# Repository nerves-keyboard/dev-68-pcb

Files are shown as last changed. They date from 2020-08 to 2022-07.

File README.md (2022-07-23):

# Dev-68

A 68-key development keyboard designed for working on the [Xebow](https://github.com/ElixirSeattle/xebow) firmware.

- [Bill of materials](https://docs.google.com/spreadsheets/d/1IPxDRe5p0AkolHPQgk4m-Z4O2ABlp4nutEiS4CgZYm4/edit?usp=sharing)

- [Layout](http://www.keyboard-layout-editor.com/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'&_w:2.25%3B&=Enter%3B&@_w:2.25%3B&=Shift&=Z&=X&=C&=V&=B&=N&=M&=%3C%0A,&=%3E%0A.&=%3F%0A%2F%2F&_w:2.75%3B&=Shift&_x:0.25%3B&=%E2%86%91%3B&@_w:1.25%3B&=Ctrl&_w:1.25%3B&=Super&_w:1.25%3B&=Alt&_w:6.25%3B&=&_w:1.25%3B&=Fn&_w:1.25%3B&=Alt&_w:1.25%3B&=Ctrl&_x:0.5%3B&=%E2%86%90&=%E2%86%93&=%E2%86%92)

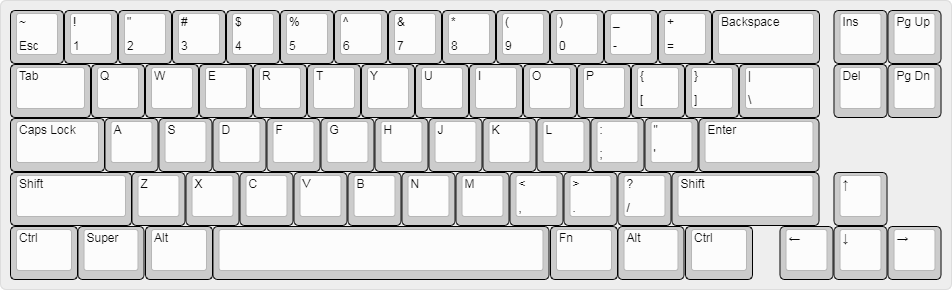
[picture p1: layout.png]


- PCB

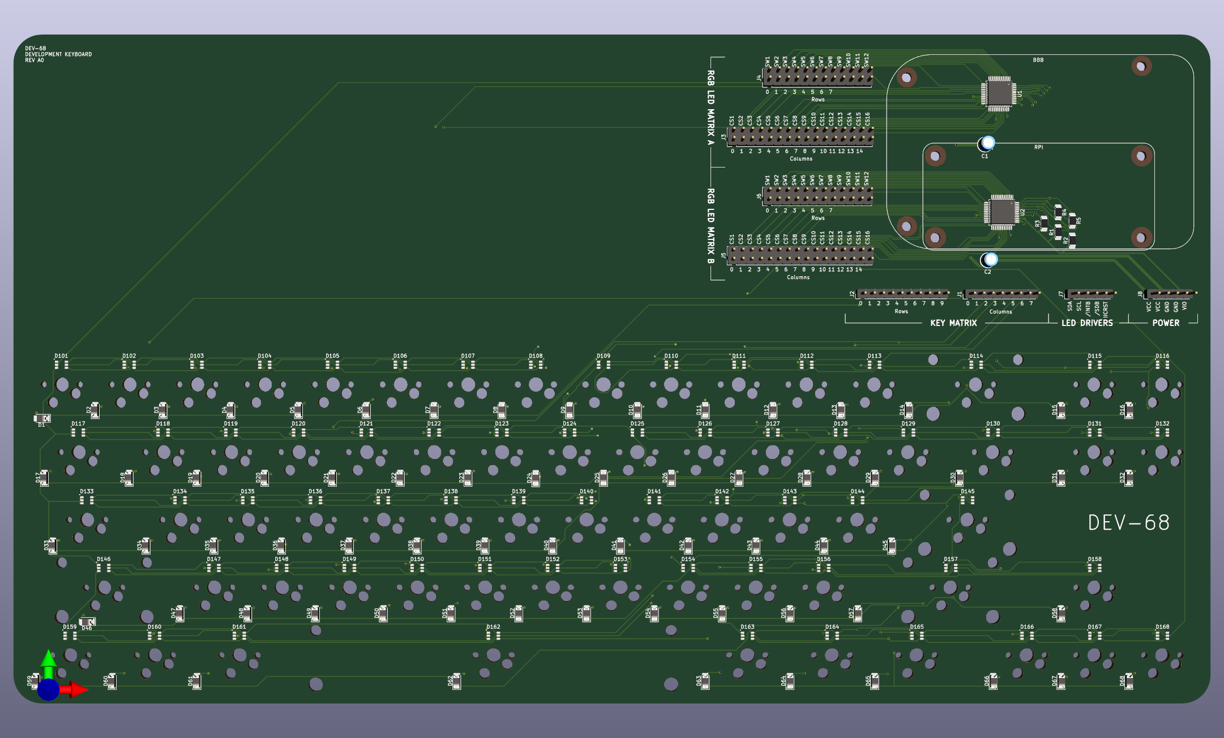
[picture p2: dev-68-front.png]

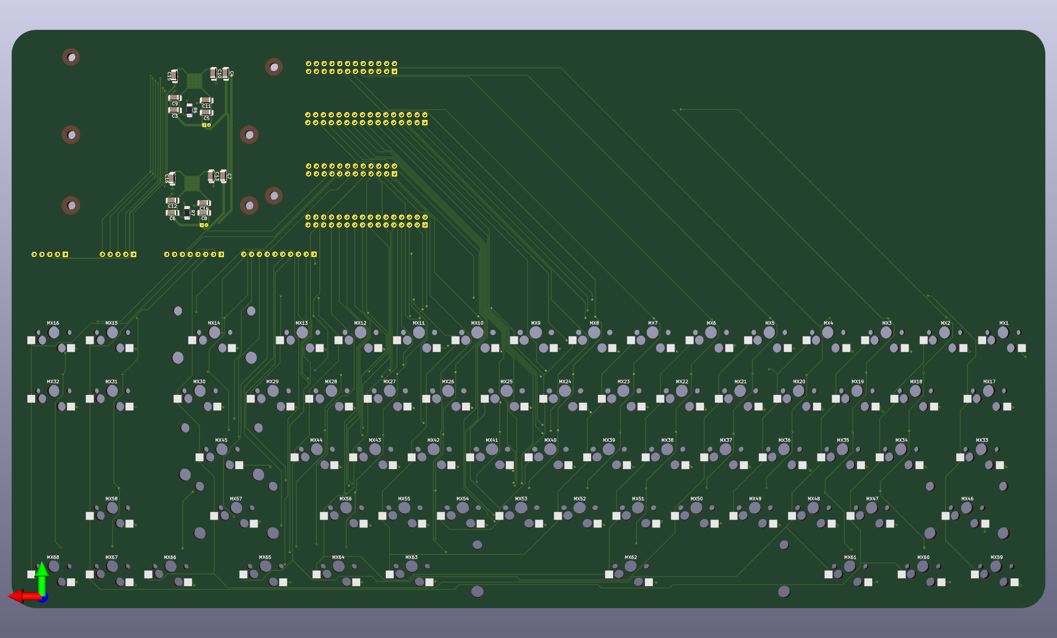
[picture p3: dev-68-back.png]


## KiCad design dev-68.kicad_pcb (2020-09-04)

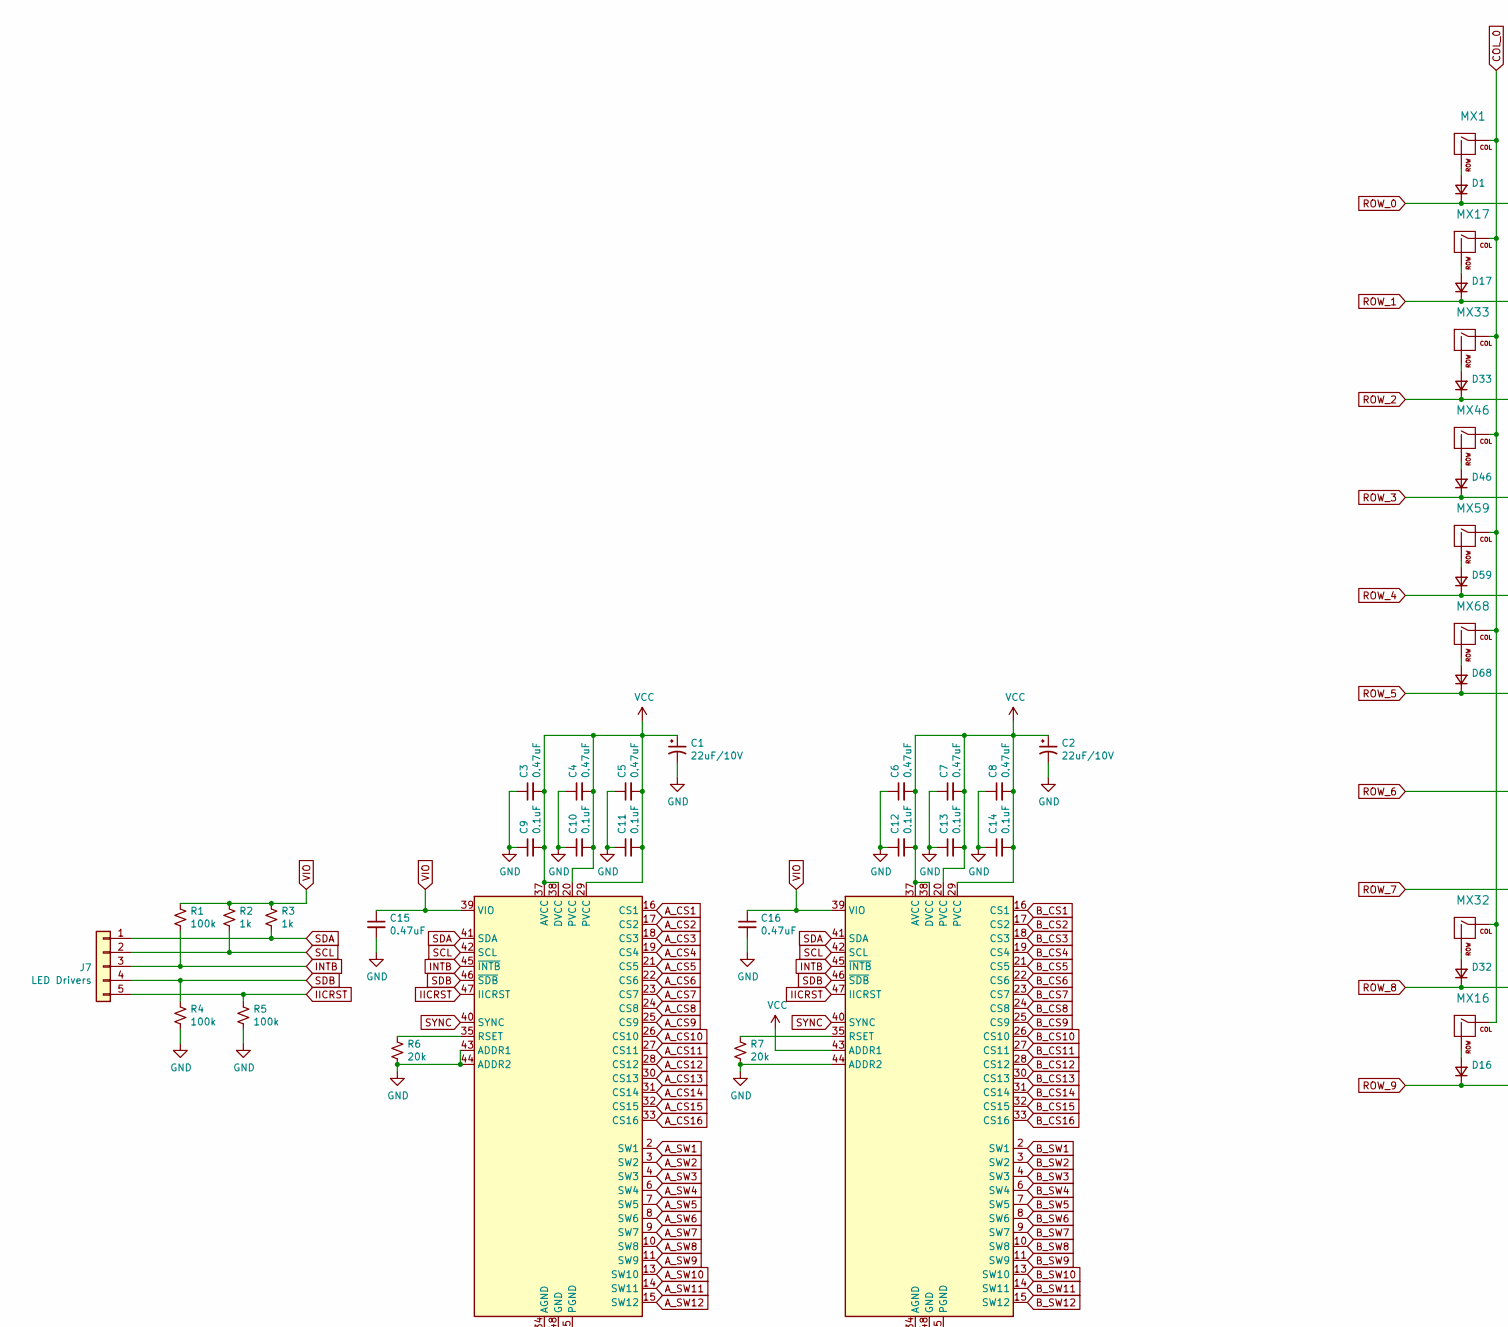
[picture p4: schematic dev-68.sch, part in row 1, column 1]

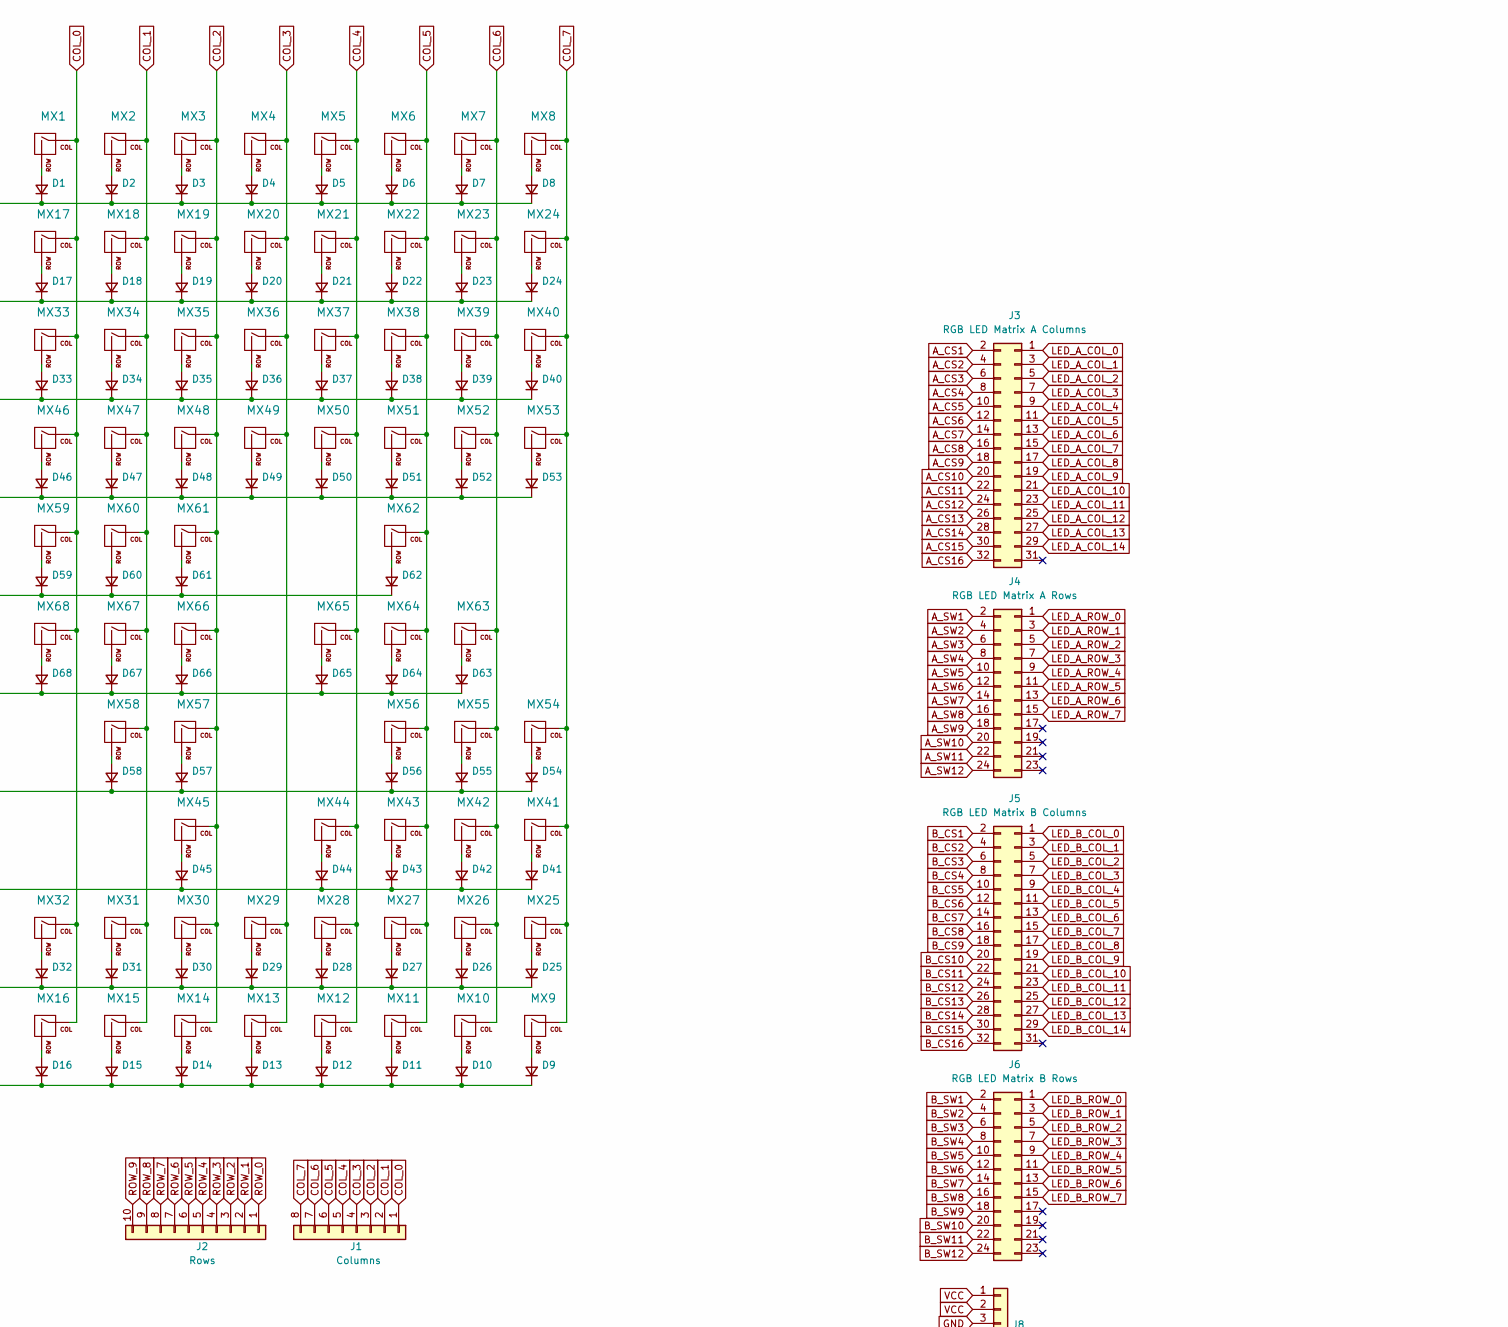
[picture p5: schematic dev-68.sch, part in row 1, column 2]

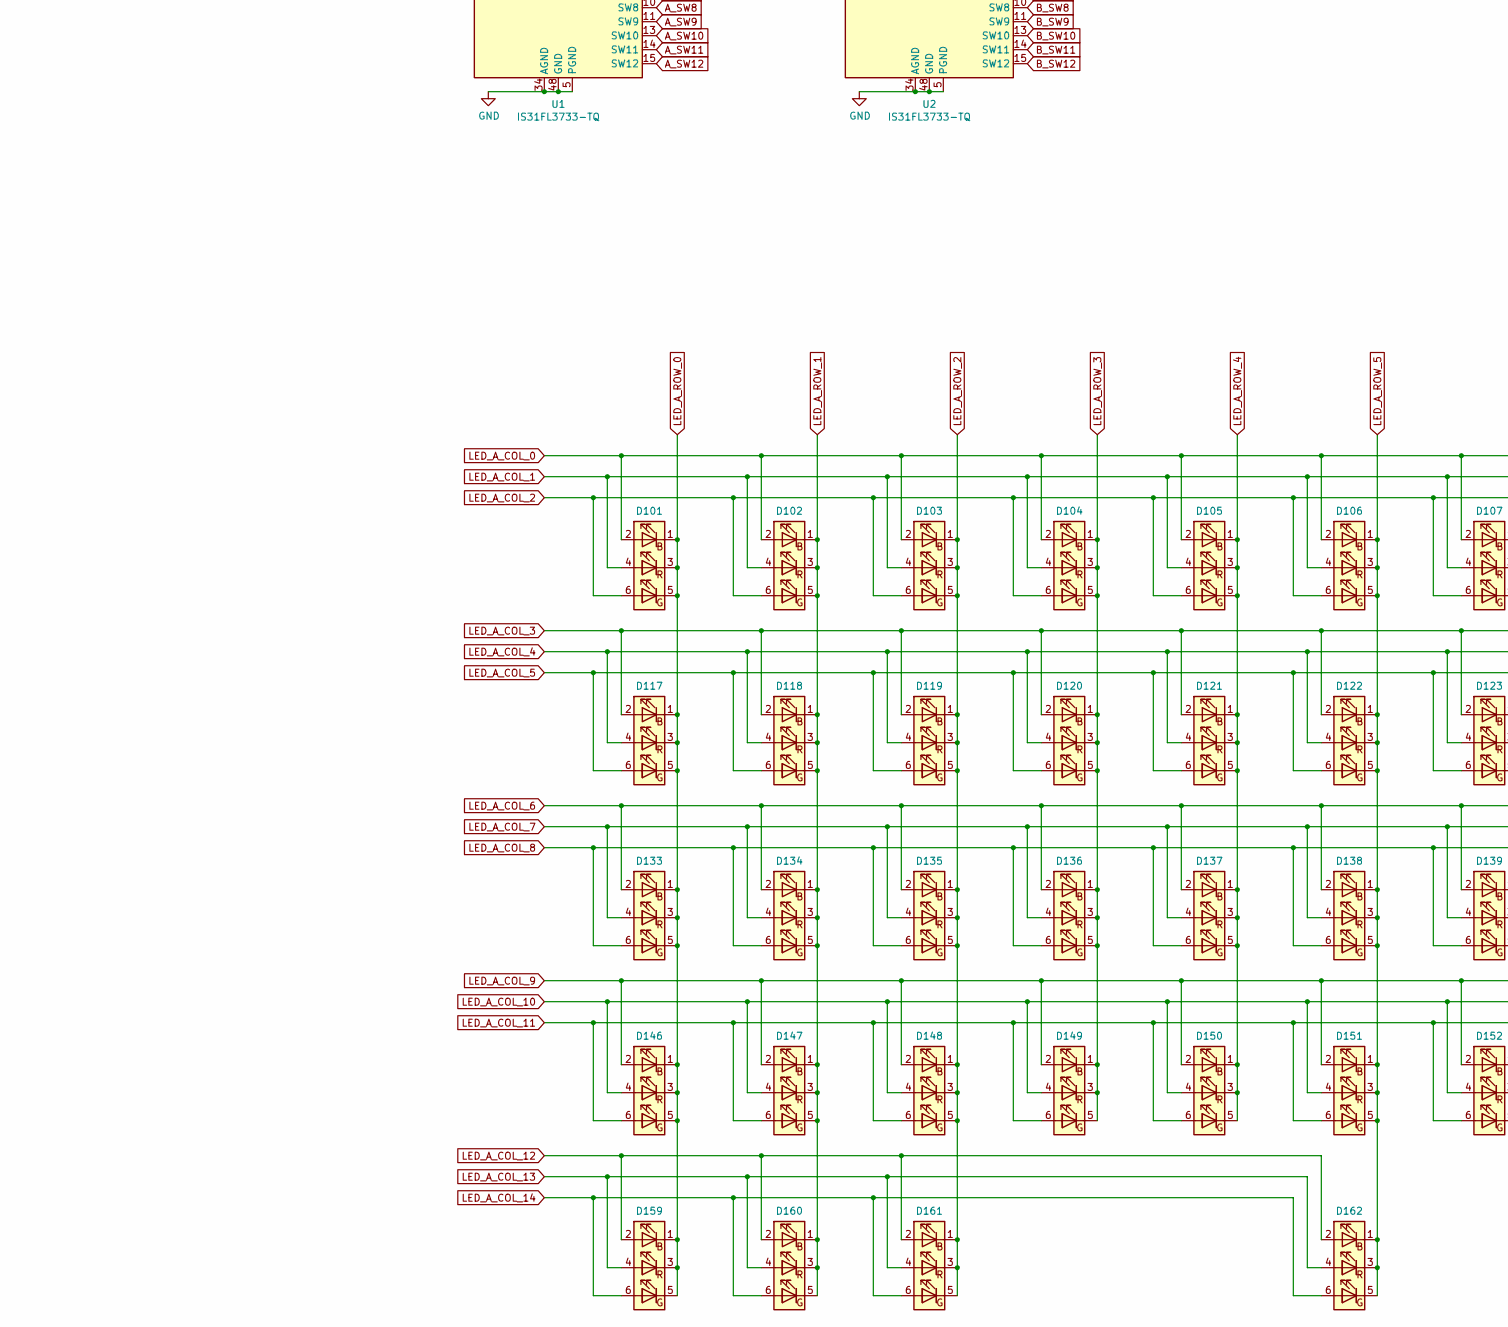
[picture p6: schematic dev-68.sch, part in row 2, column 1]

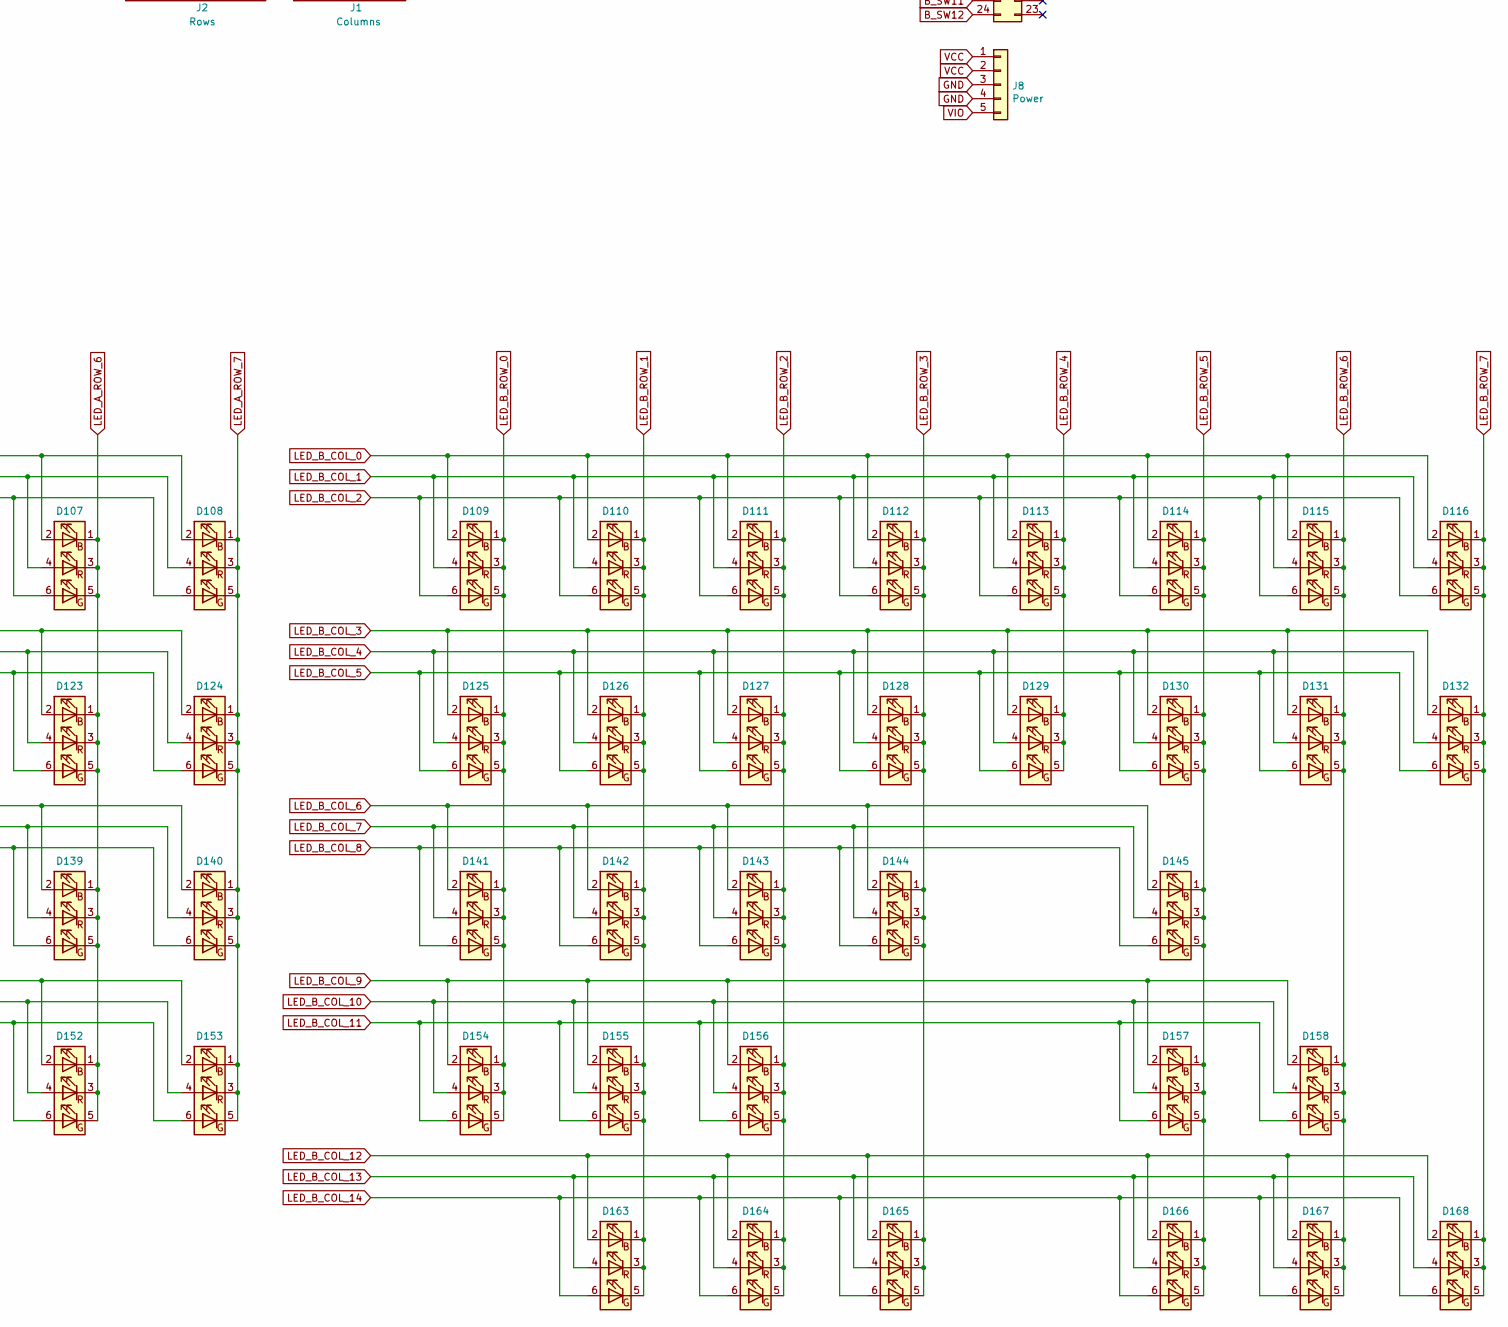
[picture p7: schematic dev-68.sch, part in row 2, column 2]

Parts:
C1, C2: 22uF/10V; CP_Radial_D4.0mm_P1.50mm
C3, C4, C5, C6, C7, C8, C15, C16: 0.47uF; C_1206_3216Metric_Pad1.42x1.75mm_HandSolder
C9, C10, C11, C12, C13, C14: 0.1uF; C_1206_3216Metric_Pad1.42x1.75mm_HandSolder
D1, D2, D3, D4, D5, D6, D7, D8, D9, D10, D11, D12, D13, D14, D15, D16, D17, D18, D19, D20, D21, D22, D23, D24, D25, D26, D27, D28, D29, D30, D31, D32, D33, D34, D35, D36, D37, D38, D39, D40, D41, D42, D43, D44, D45, D46, D47, D48, D49, D50, D51, D52, D53, D54, D55, D56, D57, D58, D59, D60, D61, D62, D63, D64, D65, D66, D67, D68: D_small; D_1206_3216Metric_Pad1.42x1.75mm_HandSolder
D101, D102, D103, D104, D105, D106, D107, D108, D109, D110, D111, D112, D113, D114, D115, D116, D117, D118, D119, D120, D121, D122, D123, D124, D125, D126, D127, D128, D129, D130, D131, D132, D133, D134, D135, D136, D137, D138, D139, D140, D141, D142, D143, D144, D145, D146, D147, D148, D149, D150, D151, D152, D153, D154, D155, D156, D157, D158, D159, D160, D161, D162, D163, D164, D165, D166, D167, D168: LED_RGB; Wurth_PLCC6
J1: Columns; PinHeader_1x08_P2.54mm_Vertical
J2: Rows; PinHeader_1x10_P2.54mm_Vertical
J3: RGB LED Matrix A Columns; PinHeader_2x16_P2.54mm_Vertical
J4: RGB LED Matrix A Rows; PinHeader_2x12_P2.54mm_Vertical
J5: RGB LED Matrix B Columns; PinHeader_2x16_P2.54mm_Vertical
J6: RGB LED Matrix B Rows; PinHeader_2x12_P2.54mm_Vertical
J7: LED Drivers; PinHeader_1x05_P2.54mm_Vertical
J8: Power; PinHeader_1x05_P2.54mm_Vertical
MX1, MX2, MX3, MX4, MX5, MX6, MX7, MX8, MX9, MX10, MX11, MX12, MX13, MX15, MX16, MX18, MX19, MX20, MX21, MX22, MX23, MX24, MX25, MX26, MX27, MX28, MX29, MX31, MX32, MX34, MX35, MX36, MX37, MX38, MX39, MX40, MX41, MX42, MX43, MX44, MX47, MX48, MX49, MX50, MX51, MX52, MX53, MX54, MX55, MX56, MX58, MX66, MX67, MX68: MX-NoLED; MXOnly-1U-Hotswap
MX14: MX-NoLED; MXOnly-2U-Hotswap-ReversedStabilizers
MX17, MX30: MX-NoLED; MXOnly-1.5U-Hotswap
MX33: MX-NoLED; MXOnly-1.75U-Hotswap
MX45, MX46: MX-NoLED; MXOnly-2.25U-Hotswap-ReversedStabilizers
MX57: MX-NoLED; MXOnly-2.75U-Hotswap-ReversedStabilizers
MX59, MX60, MX61, MX63, MX64, MX65: MX-NoLED; MXOnly-1.25U-Hotswap
MX62: MX-NoLED; MXOnly-6.25U-Hotswap-ReversedStabilizers
R1, R4, R5: 100k; R_1206_3216Metric_Pad1.42x1.75mm_HandSolder
R2, R3: 1k; R_1206_3216Metric_Pad1.42x1.75mm_HandSolder
R6, R7: 20k; R_1206_3216Metric_Pad1.42x1.75mm_HandSolder
U1, U2: IS31FL3733-TQ; TQFP-48-1EP_7x7mm_P0.5mm_EP5x5mm

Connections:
A_CS1: J3.2, U1.16 (CS1)
A_CS2: J3.4, U1.17 (CS2)
A_CS3: J3.6, U1.18 (CS3)
A_CS4: J3.8, U1.19 (CS4)
A_CS5: J3.10, U1.21 (CS5)
A_CS6: J3.12, U1.22 (CS6)
A_CS7: J3.14, U1.23 (CS7)
A_CS8: J3.16, U1.24 (CS8)
A_CS9: J3.18, U1.25 (CS9)
A_CS10: J3.20, U1.26 (CS10)
A_CS11: J3.22, U1.27 (CS11)
A_CS12: J3.24, U1.28 (CS12)
A_CS13: J3.26, U1.30 (CS13)
A_CS14: J3.28, U1.31 (CS14)
A_CS15: J3.30, U1.32 (CS15)
A_CS16: J3.32, U1.33 (CS16)
A_SW1: J4.2, U1.2 (SW1)
A_SW2: J4.4, U1.3 (SW2)
A_SW3: J4.6, U1.4 (SW3)
A_SW4: J4.8, U1.6 (SW4)
A_SW5: J4.10, U1.7 (SW5)
A_SW6: J4.12, U1.8 (SW6)
A_SW7: J4.14, U1.9 (SW7)
A_SW8: J4.16, U1.10 (SW8)
A_SW9: J4.18, U1.11 (SW9)
A_SW10: J4.20, U1.13 (SW10)
A_SW11: J4.22, U1.14 (SW11)
A_SW12: J4.24, U1.15 (SW12)
B_CS1: J5.2, U2.16 (CS1)
B_CS2: J5.4, U2.17 (CS2)
B_CS3: J5.6, U2.18 (CS3)
B_CS4: J5.8, U2.19 (CS4)
B_CS5: J5.10, U2.21 (CS5)
B_CS6: J5.12, U2.22 (CS6)
B_CS7: J5.14, U2.23 (CS7)
B_CS8: J5.16, U2.24 (CS8)
B_CS9: J5.18, U2.25 (CS9)
B_CS10: J5.20, U2.26 (CS10)
B_CS11: J5.22, U2.27 (CS11)
B_CS12: J5.24, U2.28 (CS12)
B_CS13: J5.26, U2.30 (CS13)
B_CS14: J5.28, U2.31 (CS14)
B_CS15: J5.30, U2.32 (CS15)
B_CS16: J5.32, U2.33 (CS16)
B_SW1: J6.2, U2.2 (SW1)
B_SW2: J6.4, U2.3 (SW2)
B_SW3: J6.6, U2.4 (SW3)
B_SW4: J6.8, U2.6 (SW4)
B_SW5: J6.10, U2.7 (SW5)
B_SW6: J6.12, U2.8 (SW6)
B_SW7: J6.14, U2.9 (SW7)
B_SW8: J6.16, U2.10 (SW8)
B_SW9: J6.18, U2.11 (SW9)
B_SW10: J6.20, U2.13 (SW10)
B_SW11: J6.22, U2.14 (SW11)
B_SW12: J6.24, U2.15 (SW12)
COL_0: J1.1, MX1.1 (COL), MX16.1 (COL), MX17.1 (COL), MX32.1 (COL), MX33.1 (COL), MX46.1 (COL), MX59.1 (COL), MX68.1 (COL)
COL_1: J1.2, MX2.1 (COL), MX15.1 (COL), MX18.1 (COL), MX31.1 (COL), MX34.1 (COL), MX47.1 (COL), MX58.1 (COL), MX60.1 (COL), MX67.1 (COL)
COL_2: J1.3, MX3.1 (COL), MX14.1 (COL), MX19.1 (COL), MX30.1 (COL), MX35.1 (COL), MX45.1 (COL), MX48.1 (COL), MX57.1 (COL), MX61.1 (COL), MX66.1 (COL)
COL_3: J1.4, MX4.1 (COL), MX13.1 (COL), MX20.1 (COL), MX29.1 (COL), MX36.1 (COL), MX49.1 (COL)
COL_4: J1.5, MX5.1 (COL), MX12.1 (COL), MX21.1 (COL), MX28.1 (COL), MX37.1 (COL), MX44.1 (COL), MX50.1 (COL), MX65.1 (COL)
COL_5: J1.6, MX6.1 (COL), MX11.1 (COL), MX22.1 (COL), MX27.1 (COL), MX38.1 (COL), MX43.1 (COL), MX51.1 (COL), MX56.1 (COL), MX62.1 (COL), MX64.1 (COL)
COL_6: J1.7, MX7.1 (COL), MX10.1 (COL), MX23.1 (COL), MX26.1 (COL), MX39.1 (COL), MX42.1 (COL), MX52.1 (COL), MX55.1 (COL), MX63.1 (COL)
COL_7: J1.8, MX8.1 (COL), MX9.1 (COL), MX24.1 (COL), MX25.1 (COL), MX40.1 (COL), MX41.1 (COL), MX53.1 (COL), MX54.1 (COL)
GND: C1.2, C2.2, C3.1, C4.1, C5.1, C6.1, C7.1, C8.1, C9.1, C10.1, C11.1, C12.1, C13.1, C14.1, C15.2, C16.2, J8.3, J8.4, R4.2, R5.2, R6.2, R7.2, U1.5 (PGND), U1.12 (PGND), U1.34 (AGND), U1.43 (ADDR1), U1.44 (ADDR2), U1.48 (GND), U1.49 (GND), U2.5 (PGND), U2.12 (PGND), U2.34 (AGND), U2.44 (ADDR2), U2.48 (GND), U2.49 (GND)
IICRST: J7.5, R5.1, U1.47 (IICRST), U2.47 (IICRST)
INTB: J7.3, R1.2, U1.45 (~INTB), U2.45 (~INTB)
LED_A_COL_0: D101.2 (BA), D102.2 (BA), D103.2 (BA), D104.2 (BA), D105.2 (BA), D106.2 (BA), D107.2 (BA), D108.2 (BA), J3.1
LED_A_COL_1: D101.4 (RA), D102.4 (RA), D103.4 (RA), D104.4 (RA), D105.4 (RA), D106.4 (RA), D107.4 (RA), D108.4 (RA), J3.3
LED_A_COL_2: D101.6 (GA), D102.6 (GA), D103.6 (GA), D104.6 (GA), D105.6 (GA), D106.6 (GA), D107.6 (GA), D108.6 (GA), J3.5
LED_A_COL_3: D117.2 (BA), D118.2 (BA), D119.2 (BA), D120.2 (BA), D121.2 (BA), D122.2 (BA), D123.2 (BA), D124.2 (BA), J3.7
LED_A_COL_4: D117.4 (RA), D118.4 (RA), D119.4 (RA), D120.4 (RA), D121.4 (RA), D122.4 (RA), D123.4 (RA), D124.4 (RA), J3.9
LED_A_COL_5: D117.6 (GA), D118.6 (GA), D119.6 (GA), D120.6 (GA), D121.6 (GA), D122.6 (GA), D123.6 (GA), D124.6 (GA), J3.11
LED_A_COL_6: D133.2 (BA), D134.2 (BA), D135.2 (BA), D136.2 (BA), D137.2 (BA), D138.2 (BA), D139.2 (BA), D140.2 (BA), J3.13
LED_A_COL_7: D133.4 (RA), D134.4 (RA), D135.4 (RA), D136.4 (RA), D137.4 (RA), D138.4 (RA), D139.4 (RA), D140.4 (RA), J3.15
LED_A_COL_8: D133.6 (GA), D134.6 (GA), D135.6 (GA), D136.6 (GA), D137.6 (GA), D138.6 (GA), D139.6 (GA), D140.6 (GA), J3.17
LED_A_COL_9: D146.2 (BA), D147.2 (BA), D148.2 (BA), D149.2 (BA), D150.2 (BA), D151.2 (BA), D152.2 (BA), D153.2 (BA), J3.19
LED_A_COL_10: D146.4 (RA), D147.4 (RA), D148.4 (RA), D149.4 (RA), D150.4 (RA), D151.4 (RA), D152.4 (RA), D153.4 (RA), J3.21
LED_A_COL_11: D146.6 (GA), D147.6 (GA), D148.6 (GA), D149.6 (GA), D150.6 (GA), D151.6 (GA), D152.6 (GA), D153.6 (GA), J3.23
LED_A_COL_12: D159.2 (BA), D160.2 (BA), D161.2 (BA), D162.2 (BA), J3.25
LED_A_COL_13: D159.4 (RA), D160.4 (RA), D161.4 (RA), D162.4 (RA), J3.27
LED_A_COL_14: D159.6 (GA), D160.6 (GA), D161.6 (GA), D162.6 (GA), J3.29
LED_A_ROW_0: D101.1 (BK), D101.3 (RK), D101.5 (GK), D117.1 (BK), D117.3 (RK), D117.5 (GK), D133.1 (BK), D133.3 (RK), D133.5 (GK), D146.1 (BK), D146.3 (RK), D146.5 (GK), D159.1 (BK), D159.3 (RK), D159.5 (GK), J4.1
LED_A_ROW_1: D102.1 (BK), D102.3 (RK), D102.5 (GK), D118.1 (BK), D118.3 (RK), D118.5 (GK), D134.1 (BK), D134.3 (RK), D134.5 (GK), D147.1 (BK), D147.3 (RK), D147.5 (GK), D160.1 (BK), D160.3 (RK), D160.5 (GK), J4.3
LED_A_ROW_2: D103.1 (BK), D103.3 (RK), D103.5 (GK), D119.1 (BK), D119.3 (RK), D119.5 (GK), D135.1 (BK), D135.3 (RK), D135.5 (GK), D148.1 (BK), D148.3 (RK), D148.5 (GK), D161.1 (BK), D161.3 (RK), D161.5 (GK), J4.5
LED_A_ROW_3: D104.1 (BK), D104.3 (RK), D104.5 (GK), D120.1 (BK), D120.3 (RK), D120.5 (GK), D136.1 (BK), D136.3 (RK), D136.5 (GK), D149.1 (BK), D149.3 (RK), D149.5 (GK), J4.7
LED_A_ROW_4: D105.1 (BK), D105.3 (RK), D105.5 (GK), D121.1 (BK), D121.3 (RK), D121.5 (GK), D137.1 (BK), D137.3 (RK), D137.5 (GK), D150.1 (BK), D150.3 (RK), D150.5 (GK), J4.9
LED_A_ROW_5: D106.1 (BK), D106.3 (RK), D106.5 (GK), D122.1 (BK), D122.3 (RK), D122.5 (GK), D138.1 (BK), D138.3 (RK), D138.5 (GK), D151.1 (BK), D151.3 (RK), D151.5 (GK), D162.1 (BK), D162.3 (RK), D162.5 (GK), J4.11
LED_A_ROW_6: D107.1 (BK), D107.3 (RK), D107.5 (GK), D123.1 (BK), D123.3 (RK), D123.5 (GK), D139.1 (BK), D139.3 (RK), D139.5 (GK), D152.1 (BK), D152.3 (RK), D152.5 (GK), J4.13
LED_A_ROW_7: D108.1 (BK), D108.3 (RK), D108.5 (GK), D124.1 (BK), D124.3 (RK), D124.5 (GK), D140.1 (BK), D140.3 (RK), D140.5 (GK), D153.1 (BK), D153.3 (RK), D153.5 (GK), J4.15
LED_B_COL_0: D109.2 (BA), D110.2 (BA), D111.2 (BA), D112.2 (BA), D113.2 (BA), D114.2 (BA), D115.2 (BA), D116.2 (BA), J5.1
LED_B_COL_1: D109.4 (RA), D110.4 (RA), D111.4 (RA), D112.4 (RA), D113.4 (RA), D114.4 (RA), D115.4 (RA), D116.4 (RA), J5.3
LED_B_COL_2: D109.6 (GA), D110.6 (GA), D111.6 (GA), D112.6 (GA), D113.6 (GA), D114.6 (GA), D115.6 (GA), D116.6 (GA), J5.5
LED_B_COL_3: D125.2 (BA), D126.2 (BA), D127.2 (BA), D128.2 (BA), D129.2 (BA), D130.2 (BA), D131.2 (BA), D132.2 (BA), J5.7
LED_B_COL_4: D125.4 (RA), D126.4 (RA), D127.4 (RA), D128.4 (RA), D129.4 (RA), D130.4 (RA), D131.4 (RA), D132.4 (RA), J5.9
LED_B_COL_5: D125.6 (GA), D126.6 (GA), D127.6 (GA), D128.6 (GA), D129.6 (GA), D130.6 (GA), D131.6 (GA), D132.6 (GA), J5.11
LED_B_COL_6: D141.2 (BA), D142.2 (BA), D143.2 (BA), D144.2 (BA), D145.2 (BA), J5.13
LED_B_COL_7: D141.4 (RA), D142.4 (RA), D143.4 (RA), D144.4 (RA), D145.4 (RA), J5.15
LED_B_COL_8: D141.6 (GA), D142.6 (GA), D143.6 (GA), D144.6 (GA), D145.6 (GA), J5.17
LED_B_COL_9: D154.2 (BA), D155.2 (BA), D156.2 (BA), D157.2 (BA), D158.2 (BA), J5.19
LED_B_COL_10: D154.4 (RA), D155.4 (RA), D156.4 (RA), D157.4 (RA), D158.4 (RA), J5.21
LED_B_COL_11: D154.6 (GA), D155.6 (GA), D156.6 (GA), D157.6 (GA), D158.6 (GA), J5.23
LED_B_COL_12: D163.2 (BA), D164.2 (BA), D165.2 (BA), D166.2 (BA), D167.2 (BA), D168.2 (BA), J5.25
LED_B_COL_13: D163.4 (RA), D164.4 (RA), D165.4 (RA), D166.4 (RA), D167.4 (RA), D168.4 (RA), J5.27
LED_B_COL_14: D163.6 (GA), D164.6 (GA), D165.6 (GA), D166.6 (GA), D167.6 (GA), D168.6 (GA), J5.29
LED_B_ROW_0: D109.1 (BK), D109.3 (RK), D109.5 (GK), D125.1 (BK), D125.3 (RK), D125.5 (GK), D141.1 (BK), D141.3 (RK), D141.5 (GK), D154.1 (BK), D154.3 (RK), D154.5 (GK), J6.1
LED_B_ROW_1: D110.1 (BK), D110.3 (RK), D110.5 (GK), D126.1 (BK), D126.3 (RK), D126.5 (GK), D142.1 (BK), D142.3 (RK), D142.5 (GK), D155.1 (BK), D155.3 (RK), D155.5 (GK), D163.1 (BK), D163.3 (RK), D163.5 (GK), J6.3
LED_B_ROW_2: D111.1 (BK), D111.3 (RK), D111.5 (GK), D127.1 (BK), D127.3 (RK), D127.5 (GK), D143.1 (BK), D143.3 (RK), D143.5 (GK), D156.1 (BK), D156.3 (RK), D156.5 (GK), D164.1 (BK), D164.3 (RK), D164.5 (GK), J6.5
LED_B_ROW_3: D112.1 (BK), D112.3 (RK), D112.5 (GK), D128.1 (BK), D128.3 (RK), D128.5 (GK), D144.1 (BK), D144.3 (RK), D144.5 (GK), D165.1 (BK), D165.3 (RK), D165.5 (GK), J6.7
LED_B_ROW_4: D113.1 (BK), D113.3 (RK), D113.5 (GK), D129.1 (BK), D129.3 (RK), D129.5 (GK), J6.9
LED_B_ROW_5: D114.1 (BK), D114.3 (RK), D114.5 (GK), D130.1 (BK), D130.3 (RK), D130.5 (GK), D145.1 (BK), D145.3 (RK), D145.5 (GK), D157.1 (BK), D157.3 (RK), D157.5 (GK), D166.1 (BK), D166.3 (RK), D166.5 (GK), J6.11
LED_B_ROW_6: D115.1 (BK), D115.3 (RK), D115.5 (GK), D131.1 (BK), D131.3 (RK), D131.5 (GK), D158.1 (BK), D158.3 (RK), D158.5 (GK), D167.1 (BK), D167.3 (RK), D167.5 (GK), J6.13
LED_B_ROW_7: D116.1 (BK), D116.3 (RK), D116.5 (GK), D132.1 (BK), D132.3 (RK), D132.5 (GK), D168.1 (BK), D168.3 (RK), D168.5 (GK), J6.15
unnamed: D1.2 (A), MX1.2 (ROW)
unnamed: D2.2 (A), MX2.2 (ROW)
unnamed: D3.2 (A), MX3.2 (ROW)
unnamed: D4.2 (A), MX4.2 (ROW)
unnamed: D5.2 (A), MX5.2 (ROW)
unnamed: D6.2 (A), MX6.2 (ROW)
unnamed: D7.2 (A), MX7.2 (ROW)
unnamed: D8.2 (A), MX8.2 (ROW)
unnamed: D9.2 (A), MX9.2 (ROW)
unnamed: D10.2 (A), MX10.2 (ROW)
unnamed: D11.2 (A), MX11.2 (ROW)
unnamed: D12.2 (A), MX12.2 (ROW)
unnamed: D13.2 (A), MX13.2 (ROW)
unnamed: D14.2 (A), MX14.2 (ROW)
unnamed: D15.2 (A), MX15.2 (ROW)
unnamed: D16.2 (A), MX16.2 (ROW)
unnamed: D17.2 (A), MX17.2 (ROW)
unnamed: D18.2 (A), MX18.2 (ROW)
unnamed: D19.2 (A), MX19.2 (ROW)
unnamed: D20.2 (A), MX20.2 (ROW)
unnamed: D21.2 (A), MX21.2 (ROW)
unnamed: D22.2 (A), MX22.2 (ROW)
unnamed: D23.2 (A), MX23.2 (ROW)
unnamed: D24.2 (A), MX24.2 (ROW)
unnamed: D25.2 (A), MX25.2 (ROW)
unnamed: D26.2 (A), MX26.2 (ROW)
unnamed: D27.2 (A), MX27.2 (ROW)
unnamed: D28.2 (A), MX28.2 (ROW)
unnamed: D29.2 (A), MX29.2 (ROW)
unnamed: D30.2 (A), MX30.2 (ROW)
unnamed: D31.2 (A), MX31.2 (ROW)
unnamed: D32.2 (A), MX32.2 (ROW)
unnamed: D33.2 (A), MX33.2 (ROW)
unnamed: D34.2 (A), MX34.2 (ROW)
unnamed: D35.2 (A), MX35.2 (ROW)
unnamed: D36.2 (A), MX36.2 (ROW)
unnamed: D37.2 (A), MX37.2 (ROW)
unnamed: D38.2 (A), MX38.2 (ROW)
unnamed: D39.2 (A), MX39.2 (ROW)
unnamed: D40.2 (A), MX40.2 (ROW)
unnamed: D41.2 (A), MX41.2 (ROW)
unnamed: D42.2 (A), MX42.2 (ROW)
unnamed: D43.2 (A), MX43.2 (ROW)
unnamed: D44.2 (A), MX44.2 (ROW)
unnamed: D45.2 (A), MX45.2 (ROW)
unnamed: D46.2 (A), MX46.2 (ROW)
unnamed: D47.2 (A), MX47.2 (ROW)
unnamed: D48.2 (A), MX48.2 (ROW)
unnamed: D49.2 (A), MX49.2 (ROW)
unnamed: D50.2 (A), MX50.2 (ROW)
unnamed: D51.2 (A), MX51.2 (ROW)
unnamed: D52.2 (A), MX52.2 (ROW)
unnamed: D53.2 (A), MX53.2 (ROW)
unnamed: D54.2 (A), MX54.2 (ROW)
unnamed: D55.2 (A), MX55.2 (ROW)
unnamed: D56.2 (A), MX56.2 (ROW)
unnamed: D57.2 (A), MX57.2 (ROW)
unnamed: D58.2 (A), MX58.2 (ROW)
unnamed: D59.2 (A), MX59.2 (ROW)
unnamed: D60.2 (A), MX60.2 (ROW)
unnamed: D61.2 (A), MX61.2 (ROW)
unnamed: D62.2 (A), MX62.2 (ROW)
unnamed: D63.2 (A), MX63.2 (ROW)
unnamed: D64.2 (A), MX64.2 (ROW)
unnamed: D65.2 (A), MX65.2 (ROW)
unnamed: D66.2 (A), MX66.2 (ROW)
unnamed: D67.2 (A), MX67.2 (ROW)
unnamed: D68.2 (A), MX68.2 (ROW)
unnamed: R6.1, U1.35 (RSET)
unnamed: R7.1, U2.35 (RSET)
ROW_0: D1.1 (K), D2.1 (K), D3.1 (K), D4.1 (K), D5.1 (K), D6.1 (K), D7.1 (K), D8.1 (K), J2.1
ROW_1: D17.1 (K), D18.1 (K), D19.1 (K), D20.1 (K), D21.1 (K), D22.1 (K), D23.1 (K), D24.1 (K), J2.2
ROW_2: D33.1 (K), D34.1 (K), D35.1 (K), D36.1 (K), D37.1 (K), D38.1 (K), D39.1 (K), D40.1 (K), J2.3
ROW_3: D46.1 (K), D47.1 (K), D48.1 (K), D49.1 (K), D50.1 (K), D51.1 (K), D52.1 (K), D53.1 (K), J2.4
ROW_4: D59.1 (K), D60.1 (K), D61.1 (K), D62.1 (K), J2.5
ROW_5: D63.1 (K), D64.1 (K), D65.1 (K), D66.1 (K), D67.1 (K), D68.1 (K), J2.6
ROW_6: D54.1 (K), D55.1 (K), D56.1 (K), D57.1 (K), D58.1 (K), J2.7
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

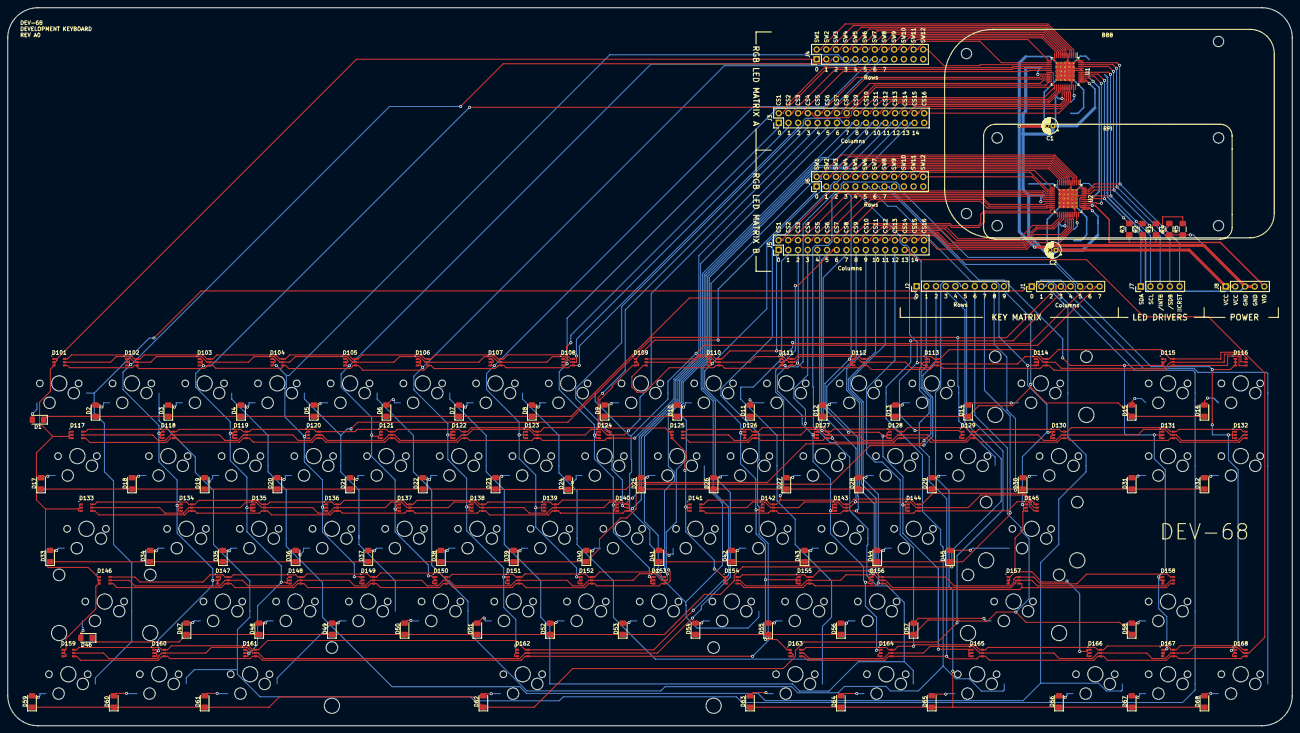
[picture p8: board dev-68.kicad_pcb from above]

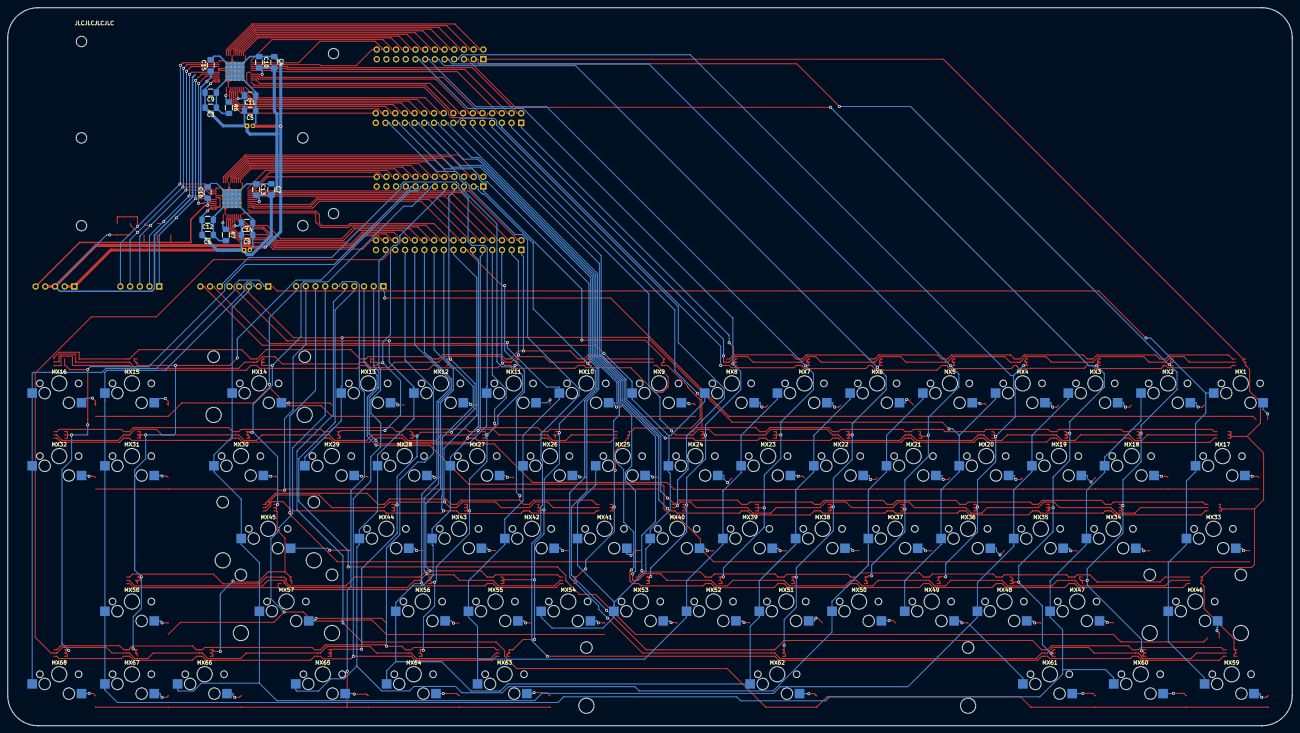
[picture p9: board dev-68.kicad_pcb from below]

Board: 2 copper layers, 336.6 x 188.1 mm, 238 parts (16 on the bottom side), 199 nets.

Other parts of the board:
J9: RPI; Raspberry_Pi_Zero_Socketed_THT_FaceDown_MountingHoles

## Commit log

2020-08-19 Better columns
    [68v2.kicad_pcb]
2020-08-24 RGB LEDs and project rename
    [68v2.kicad_pcb, 68v2.sch, dev-68.kicad_pcb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]
2020-08-24 Some tracing
    [dev-68.kicad_pcb, dev-68.sch]
2020-08-24 Undo some traces; do just the "easy" traces.
    [dev-68.kicad_pcb]
2020-08-24 Minimized vias
    [dev-68.kicad_pcb]
2020-08-24 RGB LED traces
    [dev-68.kicad_pcb]
2020-08-24 so. many. traces...
    [dev-68.kicad_pcb]
2020-08-24 LED A Matrix + Rows and Cols
    [dev-68.kicad_pcb]
2020-08-25 Finished traces
    [dev-68.kicad_pcb]
2020-08-26 Better placement
    [dev-68.kicad_pcb, dev-68.sch]
2020-08-29 Update schematic with all required 3733 components
    [dev-68.kicad_pcb, dev-68.sch]
2020-08-29 Footprints for 3733 components
    [dev-68.sch]
2020-08-29 some driver tracing
    [dev-68.kicad_pcb, dev-68.sch]
2020-08-29 Finished drivver area routing
    [dev-68.dsn, dev-68.kicad_pcb]
2020-08-30 Final? revisions
    [dev-68.dsn, dev-68.kicad_pcb]
2020-08-31 Fix silkscreen labels
    [dev-68.kicad_pcb]
2020-08-31 Small fixes
    [dev-68.dsn, dev-68.kicad_pcb]
2020-08-31 Rounded edges
    [dev-68.kicad_pcb]
2020-08-31 Fix exposed traces
    [dev-68.kicad_pcb]
2020-08-31 Add board renders to README
2020-09-01 Disconnect one side of GND guarding I2C bus. Clean up C1 & C2 traces.
    [dev-68.kicad_pcb]
2020-09-01 Don't track backup file.
2020-09-01 Don't track cache file.
2020-09-01 Fix DRC errors.
    [dev-68.kicad_pcb]
2020-09-01 Add JLCPCB order number marker.
    [dev-68.kicad_pcb]
2020-09-03 Add keys 15 and 16 back on PCB.
    [dev-68.kicad_pcb]
2020-09-03 Fix BBB silk screen outline.
    [dev-68.kicad_pcb]
2022-07-23 Add link to bill of materials.
